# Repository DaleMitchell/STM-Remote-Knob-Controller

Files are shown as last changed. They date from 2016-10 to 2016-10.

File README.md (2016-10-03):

# STM Remote Knob Controller
Over the summer of 2016 I worked with the Gupta group in the Physics Research Building at The Ohio State University. While there, I applied and expanded my engineering skills by designing and building an apparatus for the remote control of a scanning tunneling microscope.

Below is a picture of the high-voltage amplifier used for controlling the probe tip of the research group’s microscope:
<p align="center">
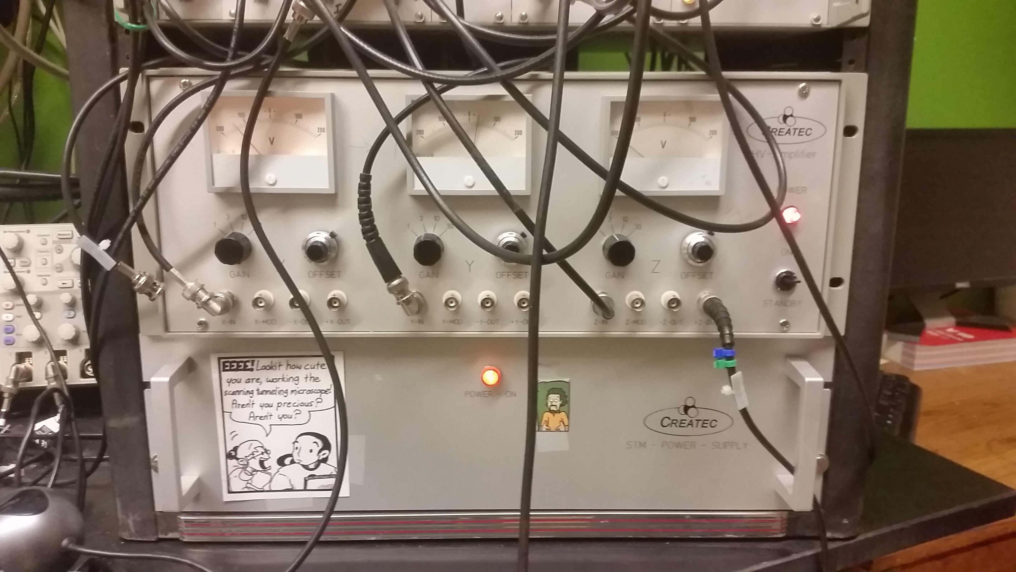
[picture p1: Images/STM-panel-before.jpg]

</p>

This is what I created:
<p align="center">
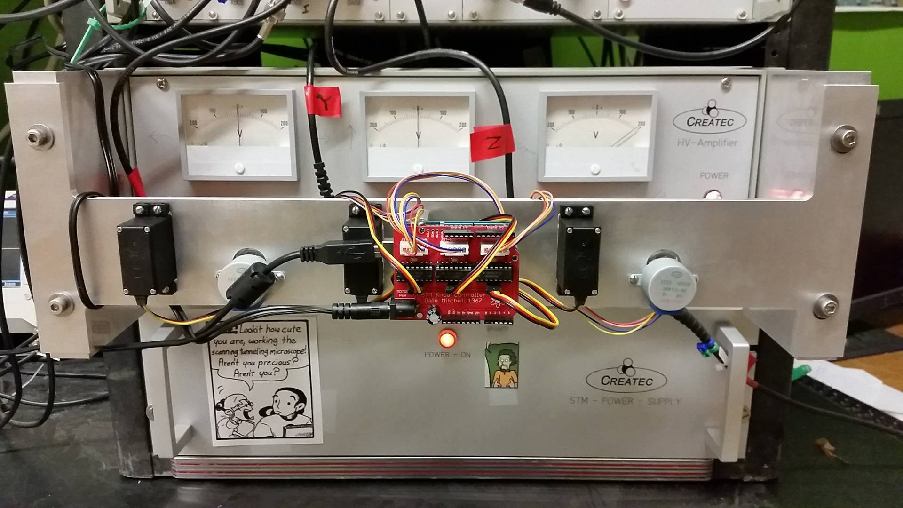
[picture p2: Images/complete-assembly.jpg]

</p>

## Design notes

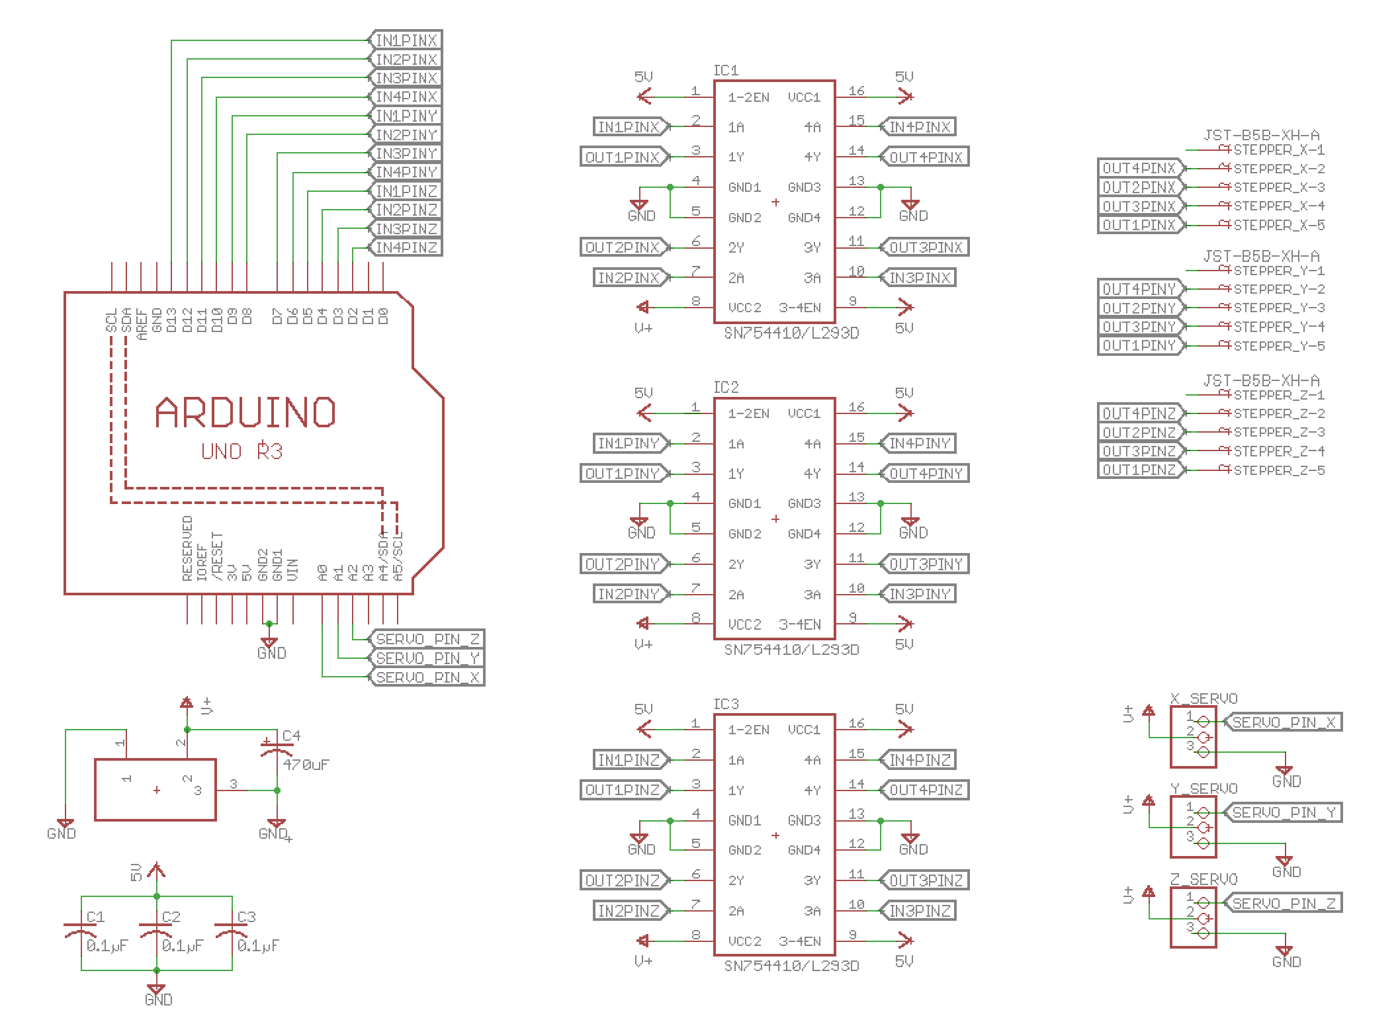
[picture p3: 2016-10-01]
Images/PCB-schematic.png

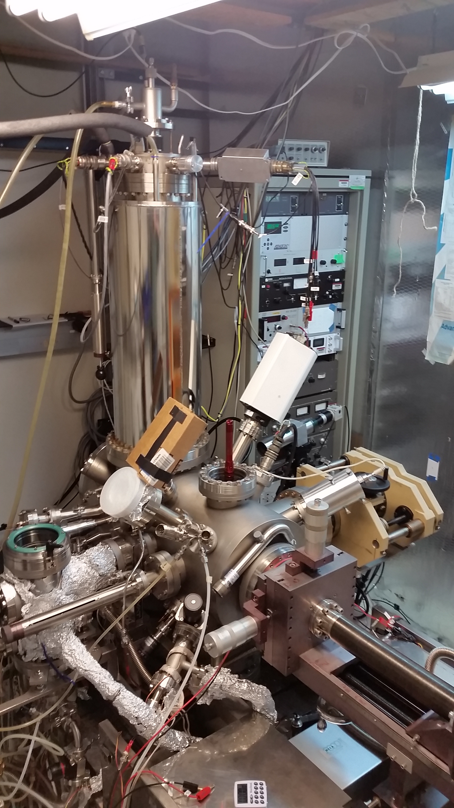
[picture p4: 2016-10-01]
Images/STM.jpg

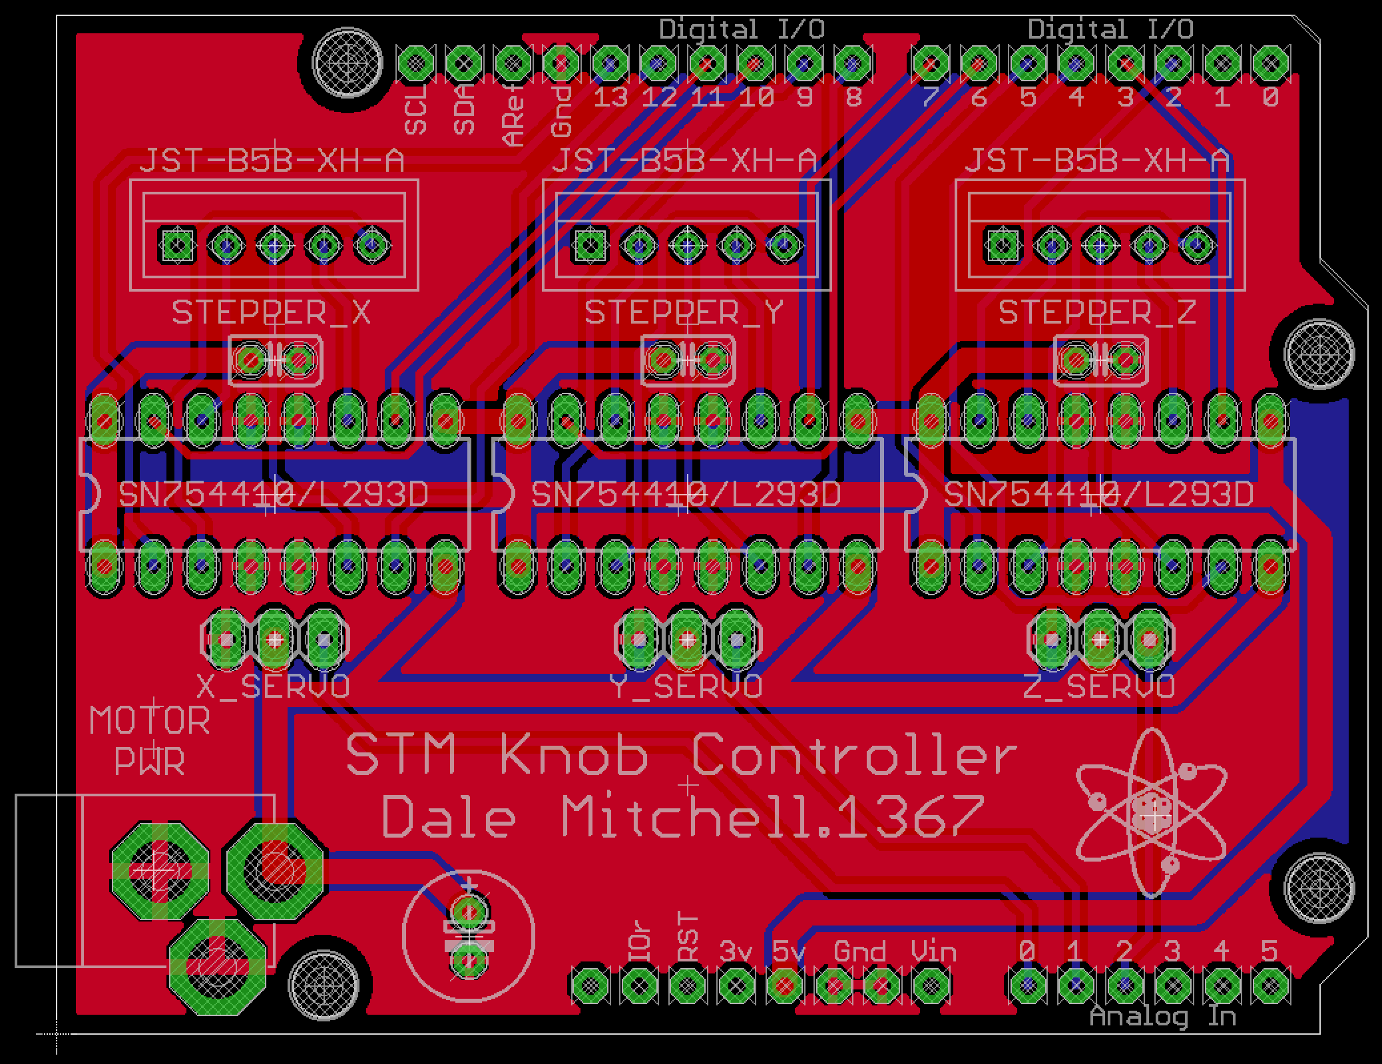
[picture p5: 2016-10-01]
Images/PCB-board.png

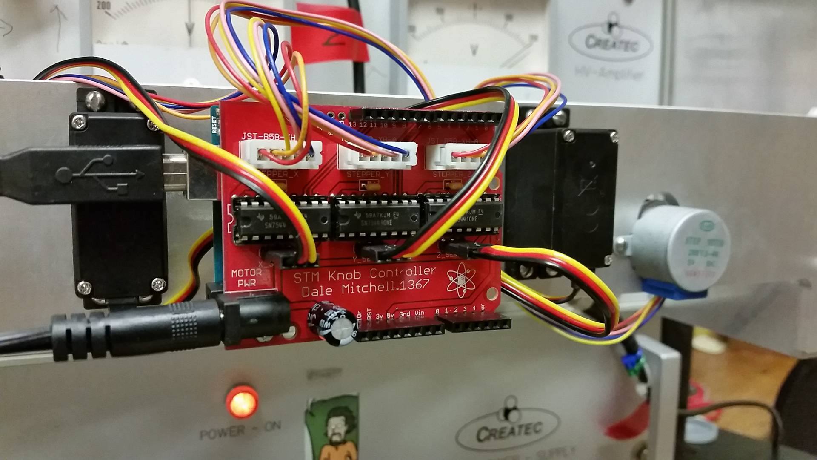
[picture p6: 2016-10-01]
Images/PCB-attached-to-motor-plate.jpg

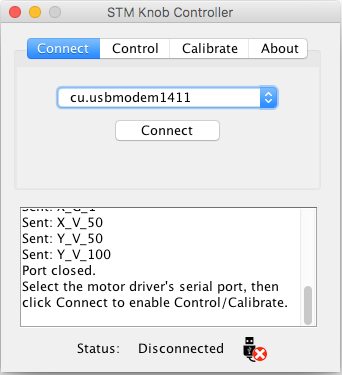
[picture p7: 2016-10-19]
Images/GUI_screenshot_connect.png

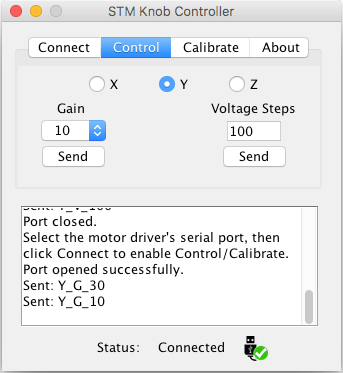
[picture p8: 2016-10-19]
Images/GUI_screenshot_control.png

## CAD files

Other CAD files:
SolidWorks/Drawing.SLDDRW

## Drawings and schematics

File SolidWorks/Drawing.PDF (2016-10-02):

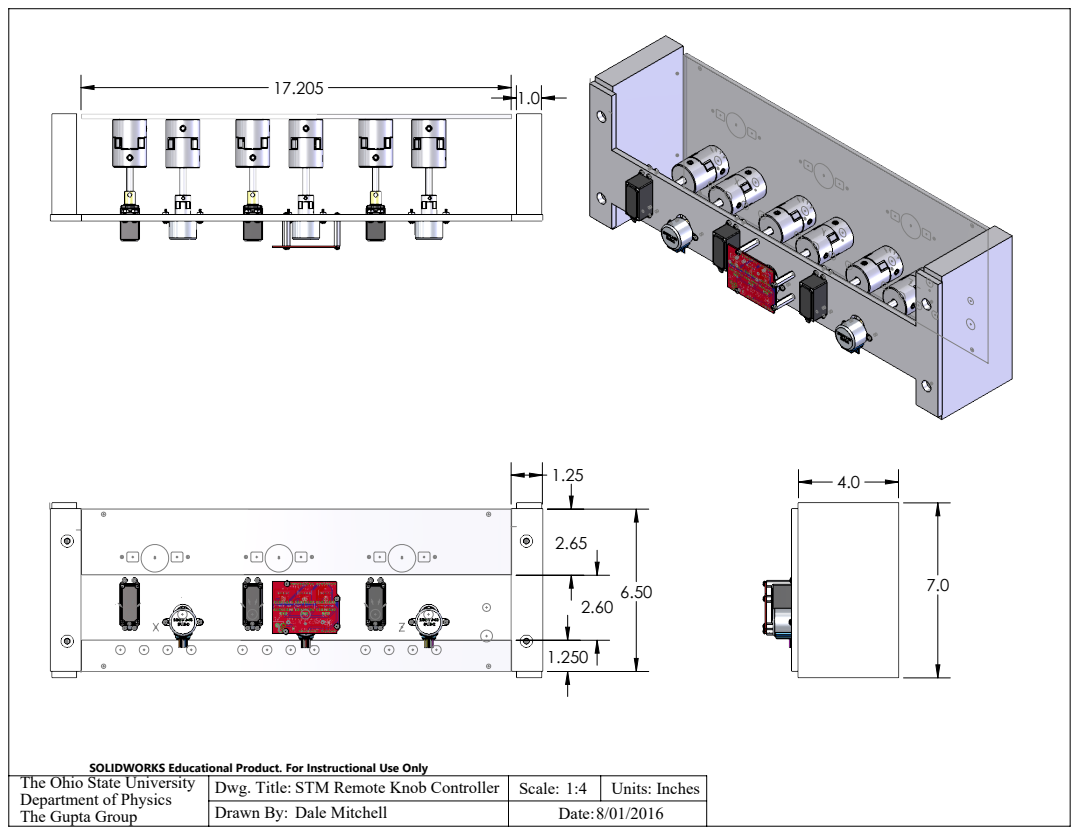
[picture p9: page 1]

SOLIDWORKS Educational Product. For Instructional Use Only

The Ohio State University Department of Physics The Gupta Group | Dwg. Title: STM Remote Knob Controller | Scale: 1:4 | Units: Inches

Drawn By: Dale Mitchell | Date: 8/01/2016

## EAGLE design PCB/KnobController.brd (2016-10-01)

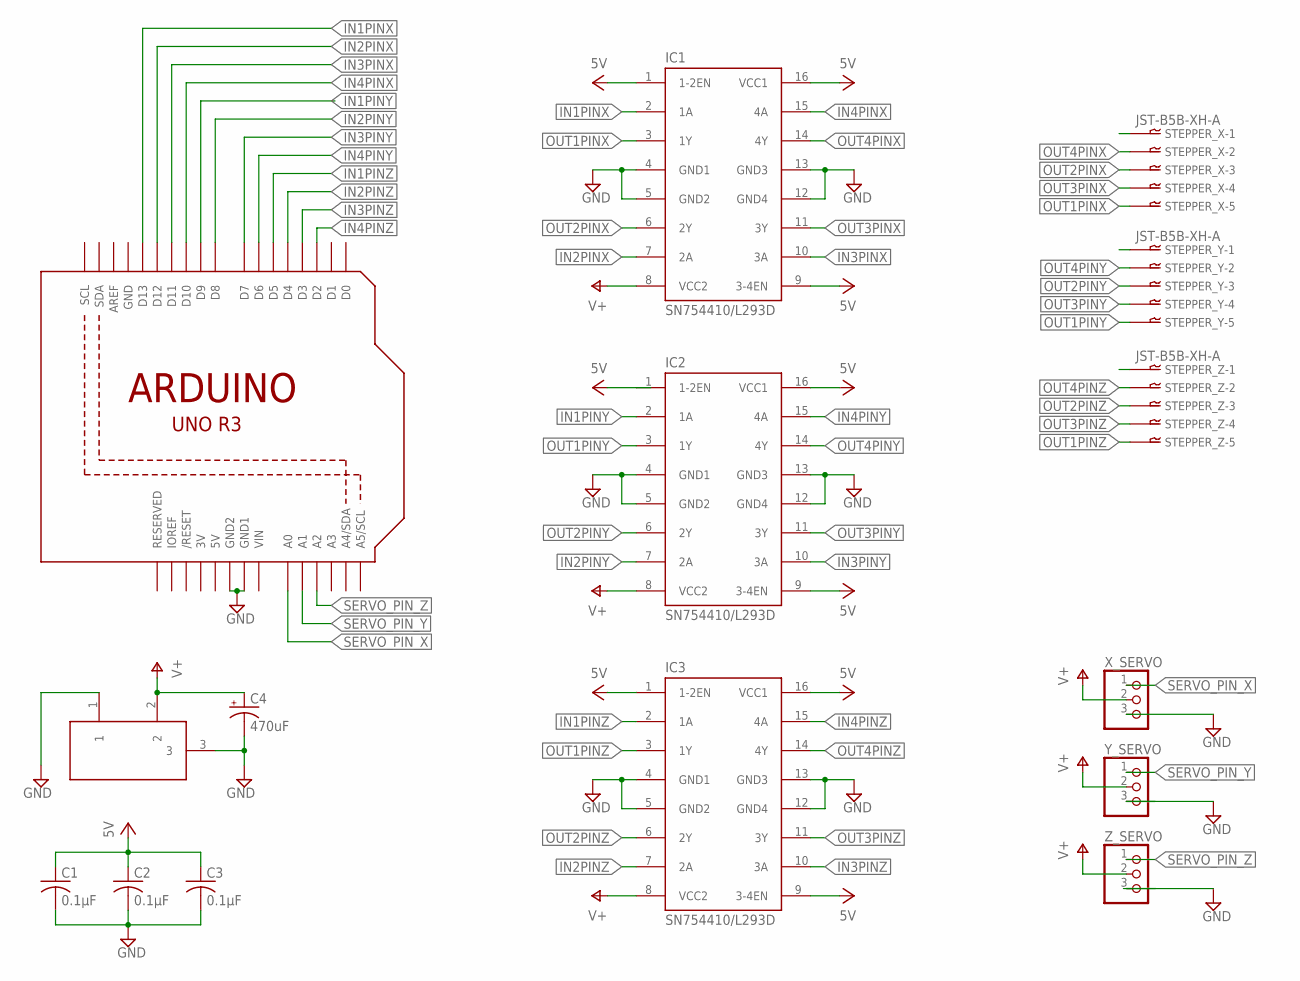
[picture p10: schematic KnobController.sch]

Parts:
C1, C2, C3: 0.1μF; C025-025X050
C4: 470uF; E2,5-7
IC1, IC2, IC3: SN754410/L293D; DIL16
PWR: MOTOR; DC-21MM
STEPPER_X: JST-B5B-XH-A; B5B-XH
STEPPER_Y: JST-B5B-XH-A; B5B-XH
STEPPER_Z: JST-B5B-XH-A; B5B-XH
U1: ARDUINOR3-BPLACE
X_SERVO: PINHD-1X3; 1X03
Y_SERVO: PINHD-1X3; 1X03
Z_SERVO: PINHD-1X3; 1X03

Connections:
3V: U1.3V
5V: C1.1, C2.1, C3.1, IC1.1 (1-2EN), IC1.9 (3-4EN), IC1.16 (VCC1), IC2.1 (1-2EN), IC2.9 (3-4EN), IC2.16 (VCC1), IC3.1 (1-2EN), IC3.9 (3-4EN), IC3.16 (VCC1), U1.5V
GND: C1.2, C2.2, C3.2, C4.-, IC1.4 (GND1), IC1.5 (GND2), IC1.12 (GND4), IC1.13 (GND3), IC2.4 (GND1), IC2.5 (GND2), IC2.12 (GND4), IC2.13 (GND3), IC3.4 (GND1), IC3.5 (GND2), IC3.12 (GND4), IC3.13 (GND3), PWR.1, PWR.3, U1.GND, U1.GND1, U1.GND2, X_SERVO.3, Y_SERVO.3, Z_SERVO.3
IN1PINX: IC1.2 (1A), U1.D13
IN1PINY: IC2.2 (1A), U1.D9
IN1PINZ: IC3.2 (1A), U1.D5
IN2PINX: IC1.7 (2A), U1.D12
IN2PINY: IC2.7 (2A), U1.D8
IN2PINZ: IC3.7 (2A), U1.D4
IN3PINX: IC1.10 (3A), U1.D11
IN3PINY: IC2.10 (3A), U1.D7
IN3PINZ: IC3.10 (3A), U1.D3
IN4PINX: IC1.15 (4A), U1.D10
IN4PINY: IC2.15 (4A), U1.D6
IN4PINZ: IC3.15 (4A), U1.D2
NULL: STEPPER_X.P$1
OUT1PINX: IC1.3 (1Y), STEPPER_X.P$5
OUT1PINY: IC2.3 (1Y), STEPPER_Y.P$5
OUT1PINZ: IC3.3 (1Y), STEPPER_Z.P$5
OUT2PINX: IC1.6 (2Y), STEPPER_X.P$3
OUT2PINY: IC2.6 (2Y), STEPPER_Y.P$3
OUT2PINZ: IC3.6 (2Y), STEPPER_Z.P$3
OUT3PINX: IC1.11 (3Y), STEPPER_X.P$4
OUT3PINY: IC2.11 (3Y), STEPPER_Y.P$4
OUT3PINZ: IC3.11 (3Y), STEPPER_Z.P$4
OUT4PINX: IC1.14 (4Y), STEPPER_X.P$2
OUT4PINY: IC2.14 (4Y), STEPPER_Y.P$2
OUT4PINZ: IC3.14 (4Y), STEPPER_Z.P$2
SERVO_PIN_X: U1.A0, X_SERVO.1
SERVO_PIN_Y: U1.A1, Y_SERVO.1
SERVO_PIN_Z: U1.A2, Z_SERVO.1
VCC: C4.+, IC1.8 (VCC2), IC2.8 (VCC2), IC3.8 (VCC2), PWR.2, X_SERVO.2, Y_SERVO.2, Z_SERVO.2
VIN: U1.VIN

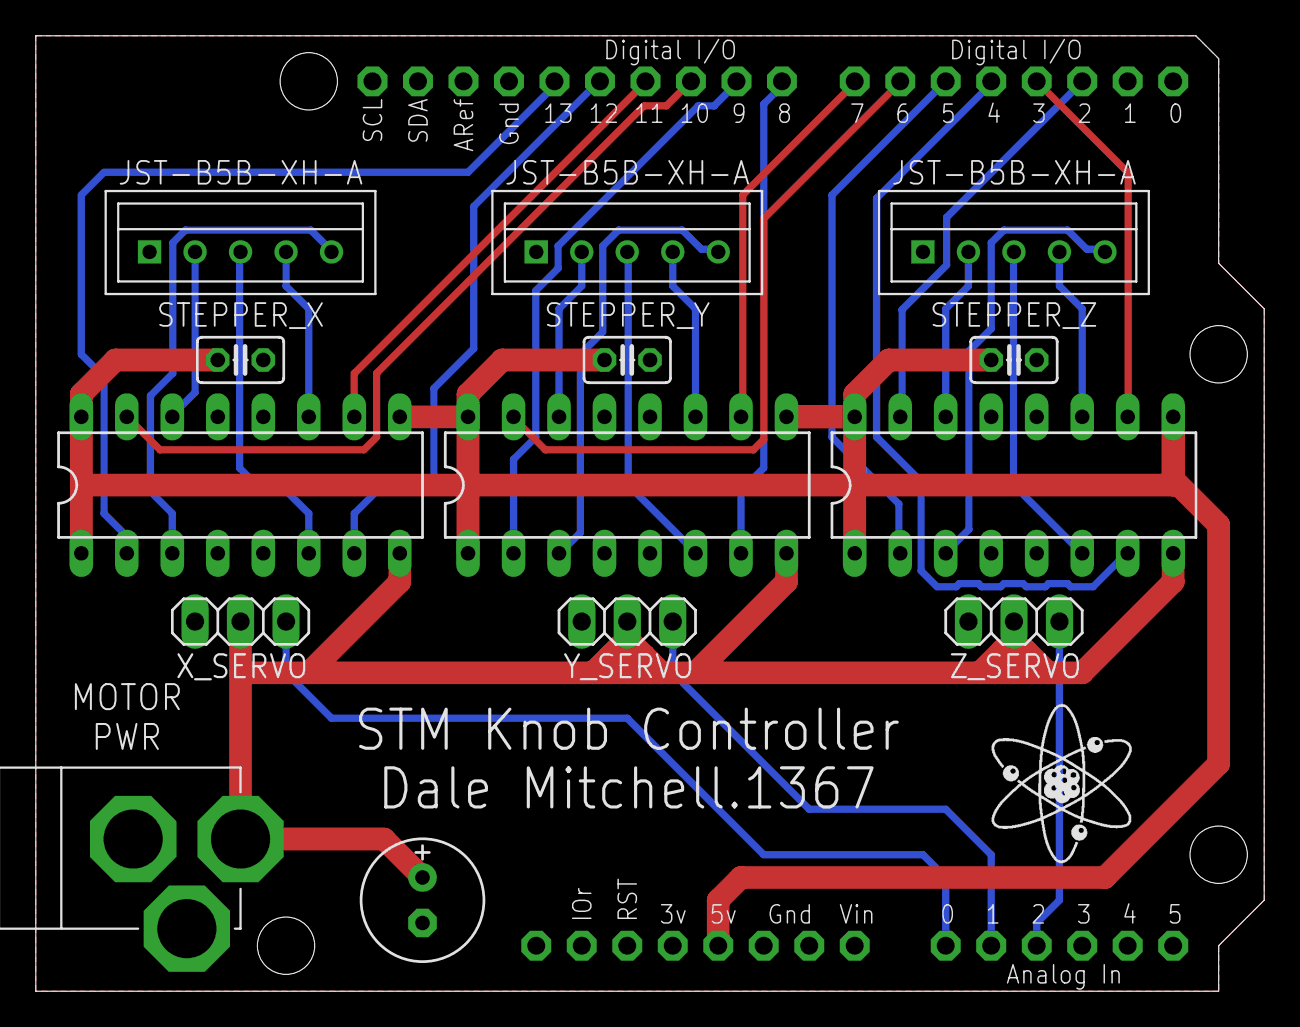
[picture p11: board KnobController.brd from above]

Board: 2 copper layers, 68.6 x 53.3 mm, 16 parts (0 on the bottom side), 30 nets.

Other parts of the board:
U$1: ATOM

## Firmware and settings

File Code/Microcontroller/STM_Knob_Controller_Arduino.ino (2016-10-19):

#include <Arduino.h>
#include <EEPROM.h>
#include <Servo.h>
#include <Stepper.h>

/*
 * Pin Constants
 */
//stepperX
int in1PinX = 13;
const int in2PinX = 12;
const int in3PinX = 11;
const int in4PinX = 10;

//stepperY
const int in1PinY = 9;
const int in2PinY = 8;
const int in3PinY = 7;
const int in4PinY = 6;

//stepperZ
const int in1PinZ = 5;
const int in2PinZ = 4;
const int in3PinZ = 3;
const int in4PinZ = 2;

//servos
const int servoPinX = A0;
const int servoPinY = A1;
const int servoPinZ = A2;

//Create Stepper objects.
Stepper stepperX(513, in1PinX, in2PinX, in3PinX, in4PinX);
Stepper stepperY(513, in1PinY, in2PinY, in3PinY, in4PinY);
Stepper stepperZ(513, in1PinZ, in2PinZ, in3PinZ, in4PinZ);

//Create Servo objects.
Servo servoX, servoY, servoZ;

/*
 * User input variables.
 */
//Settings for speed in RPM.
int motorSpeed = 20;

//Steps for stepper motors.
int stepsX = 0;
int stepsY = 0;
int stepsZ = 0;

//Degrees for servo motors.
int degreesX = 0;
int degreesY = 0;
int degreesZ = 0;

//Strings and chars to parse from input.
// (ex. X_G_10 = X-axis, Gain knob,    change gain to 10)
// (ex. Z_V_10 = Z-axis, Voltage knob, move 10 degrees)
String userInput = "";
char axisInput; // userInput.charAt(0);
char knobTypeInput; // userInput.charAt(2);
int stepsInput = 0; // userInput.substring(4);
int degreesInput = 0; // userInput.substring(4);

int calibrationData[][4] = { { 1, 85, 85, 90 },
							 { 3, 55, 55, 60 },
							 { 10, 25, 25, 25 },
							 { 30, 0, 0, 0 } };

//EEPROM for servos.
//int lastDegreesX = EEPROM.read(0);
//int lastDegreesY = EEPROM.read(1);
//int lastDegreesZ = EEPROM.read(2);

void setup() {
	pinMode(in1PinX, OUTPUT);
	pinMode(in2PinX, OUTPUT);
	pinMode(in3PinX, OUTPUT);
	pinMode(in4PinX, OUTPUT);

	pinMode(in1PinY, OUTPUT);
	pinMode(in2PinY, OUTPUT);
	pinMode(in3PinY, OUTPUT);
	pinMode(in4PinY, OUTPUT);

	pinMode(in1PinZ, OUTPUT);
	pinMode(in2PinZ, OUTPUT);
	pinMode(in3PinZ, OUTPUT);
	pinMode(in4PinZ, OUTPUT);

//	servoX.write(lastDegreesX);
//	servoY.write(lastDegreesY);
//	servoZ.write(lastDegreesZ);
//
//	servoX.attach(servoPinX);
//	servoY.attach(servoPinY);
//	servoZ.attach(servoPinZ);

	// wait for serial port to connect. Needed for native USB port only
	while (!Serial)
		;
	Serial.setTimeout(100);
	Serial.begin(115200);
	stepperX.setSpeed(motorSpeed);
	stepperY.setSpeed(motorSpeed);
	stepperZ.setSpeed(motorSpeed);

}

// Parsing the String
// (ex. X_V_10 = X-axis, Voltage knob, move 10 degrees)
// (ex. Z_G_10 = Z-axis, Gain knob,    change gain to 10)
// Add functionality to just change voltage according to gain (10 degrees * gain 5 = __ volts)

// V for Fine Knobs (Voltage), stepper.
// G for Clunky Knobs (Gain), servo motors.

void loop() {
	if (Serial.available()) {
		Serial.println(calibrationDataToString());
		Serial.println("Acknowledged connection!\n");
		Serial.println("The syntax to control knobs is the following:");
		Serial.println("Axis_Type_Position\n");
		Serial.println("Example command: ");
		Serial.println(
				"\"Y_V_50\"      Move voltage knob on Y axis 50 steps clockwise");
		Serial.println(
				"\"X_G_30\"      Move gain knob on X axis to the 30x position\n");
		userInput = Serial.readString();
		if (userInput.charAt(0) == 'L') {
			Serial.print(calibrationDataToString());
		} else if (userInput.charAt(0) == 'S') {
			Serial.setTimeout(3000);
			Serial.println("Ready for calibration input: ");
			String calibrationInput = Serial.readStringUntil('\n');
			calibrationDataToArray(calibrationInput);
			Serial.println("Success");
			Serial.setTimeout(50);
		} else if (userInput.length() >= 5) {
			axisInput = userInput.charAt(0);
			knobTypeInput = userInput.charAt(2);
			if (knobTypeInput == 'V') {
				stepsInput = userInput.substring(4).toInt();
				Serial.println(String(userInput.charAt(0)));
				switch (axisInput) {
				case 'X':
					stepperX.step(stepsInput);
					break;
				case 'Y':
					stepperY.step(stepsInput);
					break;
				case 'Z':
					stepperZ.step(stepsInput);
					break;
				default:
					Serial.println(
							"Input Error: Invalid axis, must be X, Y, or Z for charAt(0)");
					break;
				}
				Serial.println(
						"Moved " + String(stepsInput) + " steps on axis ");

			} else if (knobTypeInput == 'G') {
				boolean validGain = true;
				boolean validAxis = true;
				int calRow = userInput.substring(4).toInt();
				switch (calRow) {
				case 1:
					calRow = 0;
					break;
				case 3:
					calRow = 1;
					break;
				case 10:
					calRow = 2;
					break;
				case 30:
					calRow = 3;
					break;
				default:
					validGain = false;
					Serial.println(
							"Input Error: Invalid gain, must be 1, 3, 10, or 30 for substring(4)");
				}
				if (validGain) {
					int degrees = 0;
					Serial.println(String(userInput.charAt(0)));
					switch (axisInput) {
					case 'X':
						degrees = calibrationData[calRow][1];
						servoX.write(degrees);
						servoX.attach(servoPinX);
						delay(2000);
						servoX.detach();
						//EEPROM.update(0, degrees);
						break;
					case 'Y':
						degrees = calibrationData[calRow][2];
						servoX.write(degrees);
						servoX.attach(servoPinX);
						delay(2000);
						servoX.detach();
						//EEPROM.update(1, degrees);
						break;
					case 'Z':
						degrees = calibrationData[calRow][3];
						servoX.write(degrees);
						servoX.attach(servoPinX);
						delay(2000);
						servoX.detach();
						//EEPROM.update(2, degrees);
						break;
					default:
						validAxis = false;
						Serial.println(
								"Input Error: Invalid axis, must be X, Y, or Z for charAt(0)");
						break;
					}
					if (validAxis) {
						Serial.println(
								"Moved " + String(degrees) + " degrees on "
										+ axisInput + " axis ");
					}
				}

			} else {
				Serial.println(
						"Input Error: Invalid knobType, must be G or V for charAt(2)");
			}
		} else {
			Serial.println("Input Error: Does not satisfy minimum length of 5");
		}
	}
}

String calibrationDataToString(){
	int iMax = 3;
	int jMax = 3;
	String result;
	result = "[";
    for (int i = 0 ; i < 4 ; i++){
    	result += "[";
        for (int j = 0 ; j < 4 ; j++){
            result += calibrationData[i][j];
            if(j == jMax){
            	result += "]";
            } else {
            	result += ", ";
            }
        }
        if(i == iMax){
        	result += "]";
        } else {
        	result += ", ";
        }
    }
	return result;
}

void calibrationDataToArray(String input) {
    int row = 0;
    int col = 0;
    for (int i = 0; i < input.length(); i++) {
        if (input.charAt(i) == '[') {
            row++;
        }
    }
    row--;
    for (int i = 0;; i++) {
        if (input.charAt(i) == ',') {
            col++;
        }
        if (input.charAt(i) == ']') {
            break;
        }
    }
    col++;
    input.replace("\\[", "");
    input.replace("\\]", "");
    char inputArray[input.length() + 1];
    input.toCharArray(inputArray, input.length());
    Serial.println("test 1");
    char* s1 = strtok(inputArray, ", ");

    for (int i = 0, j = -1; i < input.length(); i++) {
        if (i % col == 0) {
            j++;
        }
        calibrationData[j][i % col] = s1[i];

    }
}

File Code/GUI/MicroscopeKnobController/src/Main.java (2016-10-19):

import java.awt.Color;
import java.awt.Desktop;
import java.awt.EventQueue;
import java.awt.Font;

import javax.swing.JFrame;
import javax.swing.JPanel;
import javax.swing.border.EmptyBorder;
import javax.swing.text.DefaultCaret;
import javax.swing.text.html.HTMLEditorKit;

import com.fazecast.jSerialComm.SerialPort;

import javax.swing.GroupLayout;
import javax.swing.GroupLayout.Alignment;
import javax.swing.ImageIcon;
import javax.swing.JButton;
import javax.swing.JComboBox;
import javax.swing.JEditorPane;
import javax.swing.JFormattedTextField;
import javax.swing.JLabel;
import javax.swing.JOptionPane;
import javax.swing.JTextField;
import javax.swing.LayoutStyle.ComponentPlacement;
import javax.swing.SwingConstants;
import javax.swing.table.DefaultTableCellRenderer;
import javax.swing.table.JTableHeader;
import javax.swing.table.TableCellEditor;
import javax.swing.text.html.HTMLDocument;
import javax.swing.UIManager;

import java.awt.event.ActionListener;
import java.awt.image.BufferedImage;
import java.io.IOException;
import java.io.InputStream;
import java.io.PrintWriter;
import java.net.URISyntaxException;
import java.util.ArrayList;
import java.util.Arrays;
import java.util.List;
import java.util.Scanner;
import java.awt.event.ActionEvent;
import javax.swing.JRadioButton;
import javax.swing.JScrollPane;
import javax.imageio.ImageIO;
import javax.imageio.stream.ImageInputStream;
import javax.swing.ButtonGroup;
import javax.swing.DefaultComboBoxModel;
import javax.swing.JTabbedPane;
import javax.swing.JList;
import javax.swing.JTextArea;
import javax.swing.event.PopupMenuListener;
import javax.swing.event.HyperlinkEvent;
import javax.swing.event.HyperlinkListener;
import javax.swing.event.PopupMenuEvent;
import javax.swing.JTable;
import javax.swing.ListSelectionModel;
import javax.swing.ScrollPaneConstants;

public class Main extends JFrame {

	private String userInput = "";
	private SerialPort[] portNames;
	static SerialPort chosenPort;
	private JComboBox<String> portList;
	private PrintWriter serialSend;
	private Scanner serialRead;
	private boolean userToggleSerial;

	private static final long serialVersionUID = 5461360408065689724L;
	private JTabbedPane tabbedPane;
	private JPanel contentPane;
	private JLabel lblNewLabel;
	private JButton btnSendSteps;
	private JButton btnSendGain;
	private JButton btnConnect;
	private JTextField textField_Steps;
	private final ButtonGroup buttonGroup = new ButtonGroup();
	private JRadioButton rdbtnX;
	private JRadioButton rdbtnY;
	private JRadioButton rdbtnZ;
	private JList<Object> list;
	private JLabel lblGain;
	private JComboBox<String> gainComboBox;
	private final static JTextArea textArea = new JTextArea();
	DefaultCaret caret = (DefaultCaret) textArea.getCaret();

	private static JScrollPane scroll = new JScrollPane(textArea, JScrollPane.VERTICAL_SCROLLBAR_ALWAYS,
			JScrollPane.HORIZONTAL_SCROLLBAR_NEVER);
	private JLabel lblStatusImage;
	private JLabel lblConnectStatus;

	private List<BufferedImage> images;
	private JPanel panelAbout;
	private JPanel panelCalibrate;
	private JEditorPane editorPaneAbout;
	private JFormattedTextField fieldTable;
	private JButton btnSave;
	private JButton btnLoad;
	private String[] gainPos = { "1", "3", "10", "30" };
	private JTable table;
	private JButton btnSaveDefault;

	/**
	 * Launch the application.
	 */
	public static void main(String[] args) {
		EventQueue.invokeLater(new Runnable() {
			public void run() {
				try {
					Main frame = new Main();
					frame.setVisible(true);
				} catch (Exception e) {
					e.printStackTrace();
				}
			}
		});
	}

	public Main() {
		setResizable(false);
		initComponents();
		createEvents();
	}

	private void initComponents() {
		setDefaultLookAndFeelDecorated(true);
		setTitle("STM Knob Controller");
		setDefaultCloseOperation(JFrame.EXIT_ON_CLOSE);
		setBounds(100, 100, 339, 371);
		contentPane = new JPanel();
		contentPane.setBorder(new EmptyBorder(5, 5, 5, 5));
		setContentPane(contentPane);

		try {
			InputStream iconImageFile = Main.class.getResourceAsStream("/icons/atom.png");
			ImageInputStream iconImageInput = ImageIO.createImageInputStream(iconImageFile);

			InputStream disconnectedImageFile = Main.class.getResourceAsStream("/icons/disconnected_small.png");
			ImageInputStream disconnectedImageInput = ImageIO.createImageInputStream(disconnectedImageFile);

			InputStream connectedImageFile = Main.class.getResourceAsStream("/icons/connected_small.png");
			ImageInputStream connectedImageInput = ImageIO.createImageInputStream(connectedImageFile);

			setIconImage(ImageIO.read(iconImageInput));
			images = new ArrayList<>(2);
			images.add(ImageIO.read(disconnectedImageInput));
			images.add(ImageIO.read(connectedImageInput));
		} catch (IOException e) {
			e.printStackTrace();
		}

		tabbedPane = new JTabbedPane(JTabbedPane.TOP);

		list = new JList<Object>();

		caret.setUpdatePolicy(DefaultCaret.ALWAYS_UPDATE);
		textArea.append("Select the motor driver's serial port, then \n" + "click Connect to enable Control/Calibrate.\n");
		textArea.setEditable(false);
		textArea.setBounds(6, 136, 332, 121);

		JLabel lblStatus = new JLabel("Status:", SwingConstants.CENTER);

		lblStatusImage = new JLabel("");
		lblStatusImage.setIcon(new ImageIcon(images.get(0)));

		lblConnectStatus = new JLabel("Disconnected");
		lblConnectStatus.setHorizontalAlignment(SwingConstants.CENTER);
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
